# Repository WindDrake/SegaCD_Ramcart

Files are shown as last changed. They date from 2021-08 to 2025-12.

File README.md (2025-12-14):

# SegaCD_Ramcart
 Sega Genesis/Megadrive CD Back-up RAM Cart

 Design done in Kicad 5.1.10 with Digikey libraries. If you want to edit it, you'll need those libraries as well as these files.

 Board tested working 9/3/21 after fixing A20/A22 accidental swap @ U4.

 PCB revision 1.1 has this fixed.
 PCB revision 1.2 adds R2 to make sure the SRAM goes into sleep mode. The BOM has also changed.

 RAM Cart tested 9/3 with Dark Wizard and does not have the save corruption issue that the Castlemania Ultra cart has.

 CSV Format BOM & Gerbers added 10/30/21.

 If you have an Etsy/eBay/Aliexpress/etc. cartridge and are experiencing low battery life, you'll need to swap parts at R1, D1, and U2 with the parts listed in the current BOM. You'll also need to add a 10k resistor from U2 Pin 22 to D1 Pin 3 (the single pin on top).

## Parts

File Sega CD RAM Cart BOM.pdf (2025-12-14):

Source: | \Sega CD Ram Cart\Sega CD RAM Cart.sch
Date: | 10/30/2021 13:53
Tool: | Eeschema (5.1.10)-1
Generator: | \bin\scripting\plugins/bom_csv_grouped_by_value.py
Component Count: | 21
Reference(s) | Value | LibPart | Footprint | Digikey PN
BT1 | Battery_Cell | Sega_Genesis:Battery_Cell | BU2450SM:BAT_BU2450SM-JJ-G | BU2450SM-JJ-GTR
C1-C7 | 0.1uF | Device:C | Capacitor_SMD:C_1206_3216Metric_Pad1.33x1.80mm_HandSolder | C1206C104K4RACTU
C8 | 22uF 25v | Device:CP | Capacitor_THT:CP_Radial_D5.0mm_P2.00mm | 25ML22MEFC5X5
D1 | SDM40E20LC-7 | Sega_Genesis:BAT5405E | digikey-footprints:SOT-23-3 | SDM40E20LC-7
H1, H2 | MountingHole | Mechanical:MountingHole | Sega CD RAM Cart:MountingHole_6.2mm
J1 | Genesis_Edge_Connector | Sega_Genesis:Genesis_Edge_Connector | Sega CD RAM Cart:Genesis_Card_Edge
R1, R2 | 10K | Device:R | Resistor_SMD:R_0805_2012Metric_Pad1.20x1.40mm_HandSolder | RMCF0805FT10K0
U1 | 74LS30 | 74xx:74LS30 | digikey-footprints:SOIC-14_W3.9mm | SN74LS30DR
U2 | CY62148ELL-55SXI | Memory_RAM:IS61C5128AS-25QLI | Package_SO:SSOP-32_11.305x20.495mm_P1.27mm | CY62148ELL-55SXI
U3 | 74LS30 | 74xx:74LS30 | digikey-footprints:SOIC-14_W3.9mm | SN74LS30DR
U4 | 74LS138 | 74xx:74LS138 | digikey-footprints:SOIC-16_W3.90mm | SN74LS138DR
U5 | 74LS32 | 74xx:74LS32 | digikey-footprints:SOIC-14_W3.9mm | SN74LS32DR
U6 | 74LS74 | 74xx:74LS74 | digikey-footprints:SOIC-14_W3.9mm | SN74LS74ADR
U7 | 74LS245 | 74xx:74LS245 | digikey-footprints:SSOP-20_W5.3mm | SN74LS245DBR

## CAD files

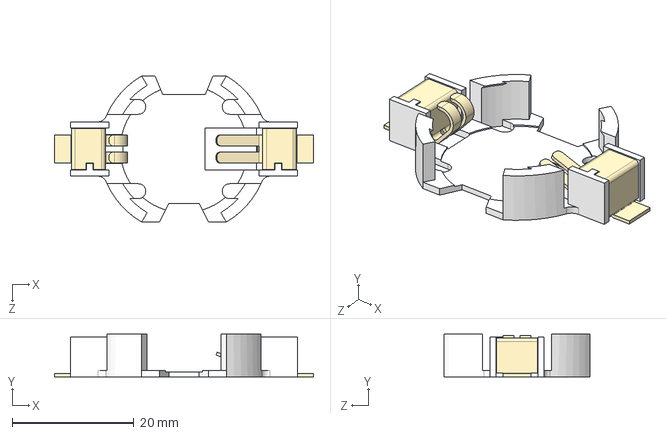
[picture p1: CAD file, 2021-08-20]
BU2450SM/BU2450SM-JJ-G.step
42.5 x 7.00 x 24.0 mm

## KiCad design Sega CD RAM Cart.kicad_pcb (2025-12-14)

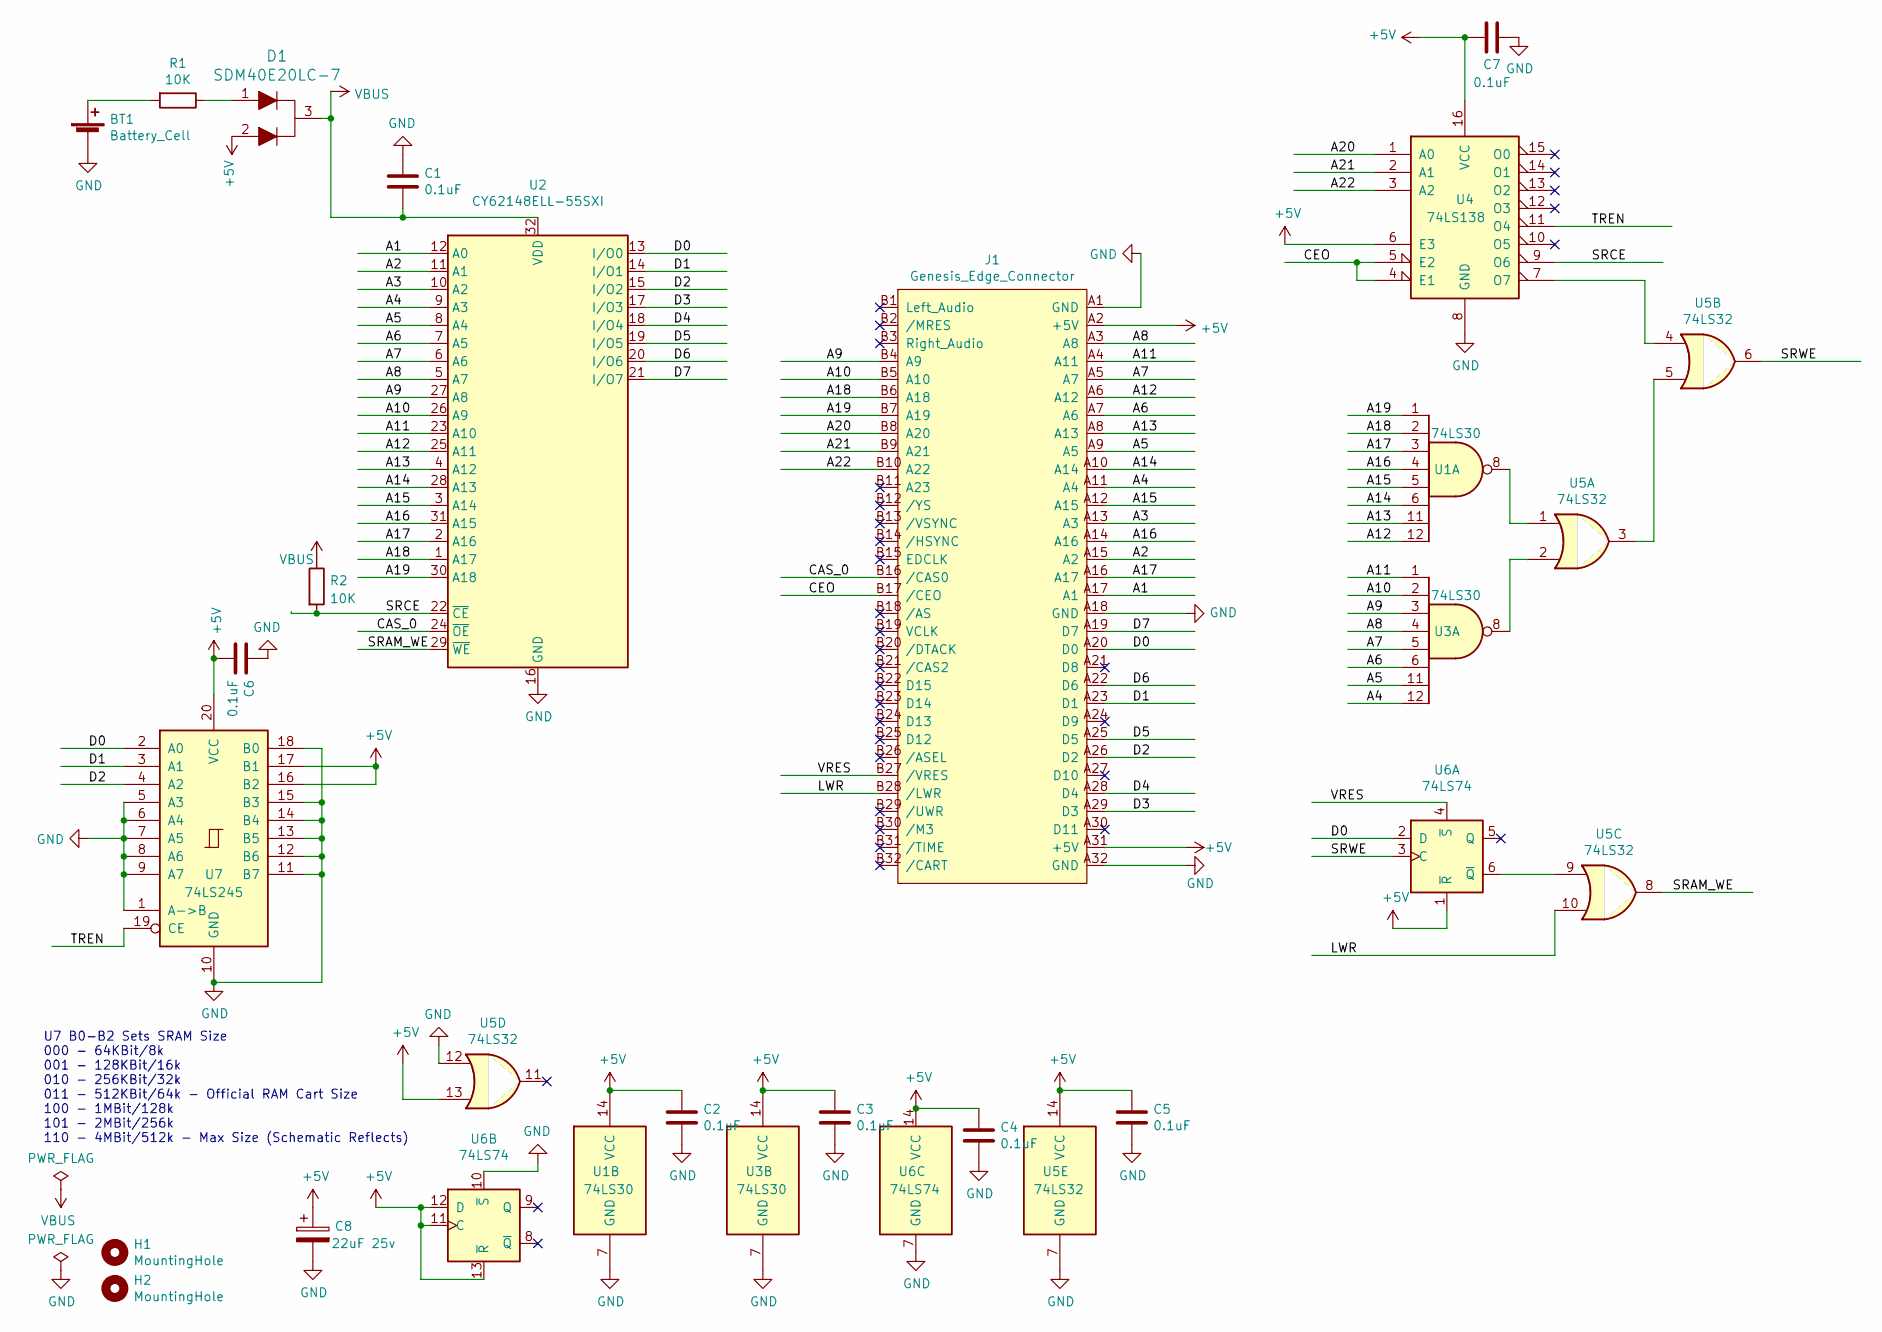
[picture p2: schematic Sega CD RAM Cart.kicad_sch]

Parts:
BT1: Battery_Cell; BAT_BU2450SM-JJ-G; Digikey PN BU2450SM-JJ-GTR
C1, C2, C3, C4, C5, C6, C7: 0.1uF; C_1206_3216Metric_Pad1.33x1.80mm_HandSolder; Digikey PN C1206C104K4RACTU
C8: 22uF 25v; CP_Radial_D5.0mm_P2.00mm; Digikey PN 25ML22MEFC5X5
D1: SDM40E20LC-7; SOT-23-3; Digikey PN SDM40E20LC-7
H1, H2: MountingHole; MountingHole_6.2mm
J1: Genesis_Edge_Connector; Genesis_Card_Edge
R1, R2: 10K; R_0805_2012Metric_Pad1.20x1.40mm_HandSolder; Digikey PN RMCF0805FT10K0
U1, U3: 74LS30; SOIC-14_W3.9mm; Digikey PN SN74LS30DR
U2: CY62148ELL-55SXI; SSOP-32_11.305x20.495mm_P1.27mm; Digikey PN CY62148ELL-55SXI
U4: 74LS138; SOIC-16_W3.90mm; Digikey PN SN74LS138DR
U5: 74LS32; SOIC-14_W3.9mm; Digikey PN SN74LS32DR
U6: 74LS74; SOIC-14_W3.9mm; Digikey PN SN74LS74ADR
U7: 74LS245; SSOP-20_W5.3mm; Digikey PN SN74LS245DBR

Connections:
+5V: C2.1, C3.1, C4.1, C5.1, C6.2, C7.2, C8.1, D1.2, J1.A2 (+5V), J1.A31 (+5V), U1.14 (VCC), U3.14 (VCC), U4.6 (E3), U4.16 (VCC), U5.13, U5.14 (VCC), U6.1 (~R), U6.11 (C), U6.12 (D), U6.13 (~R), U6.14 (VCC), U7.16 (B2), U7.17 (B1), U7.20 (VCC)
/A1: J1.A17 (A1), U2.12 (A0)
/A2: J1.A15 (A2), U2.11 (A1)
/A3: J1.A13 (A3), U2.10 (A2)
/A4: J1.A11 (A4), U2.9 (A3), U3.12
/A5: J1.A9 (A5), U2.8 (A4), U3.11
/A6: J1.A7 (A6), U2.7 (A5), U3.6
/A7: J1.A5 (A7), U2.6 (A6), U3.5
/A8: J1.A3 (A8), U2.5 (A7), U3.4
/A9: J1.B4 (A9), U2.27 (A8), U3.3
/A10: J1.B5 (A10), U2.26 (A9), U3.2
/A11: J1.A4 (A11), U2.23 (A10), U3.1
/A12: J1.A6 (A12), U1.12, U2.25 (A11)
/A13: J1.A8 (A13), U1.11, U2.4 (A12)
/A14: J1.A10 (A14), U1.6, U2.28 (A13)
/A15: J1.A12 (A15), U1.5, U2.3 (A14)
/A16: J1.A14 (A16), U1.4, U2.31 (A15)
/A17: J1.A16 (A17), U1.3, U2.2 (A16)
/A18: J1.B6 (A18), U1.2, U2.1 (A17)
/A19: J1.B7 (A19), U1.1, U2.30 (A18)
/A20: J1.B8 (A20), U4.1 (A0)
/A21: J1.B9 (A21), U4.2 (A1)
/A22: J1.B10 (A22), U4.3 (A2)
/CAS_0: J1.B16 (/CAS0), U2.24 (~OE)
/CEO: J1.B17 (/CEO), U4.4 (E1), U4.5 (E2)
/D0: J1.A20 (D0), U2.13 (I/O0), U6.2 (D), U7.2 (A0)
/D1: J1.A23 (D1), U2.14 (I/O1), U7.3 (A1)
/D2: J1.A26 (D2), U2.15 (I/O2), U7.4 (A2)
/D3: J1.A29 (D3), U2.17 (I/O3)
/D4: J1.A28 (D4), U2.18 (I/O4)
/D5: J1.A25 (D5), U2.19 (I/O5)
/D6: J1.A22 (D6), U2.20 (I/O6)
/D7: J1.A19 (D7), U2.21 (I/O7)
/LWR: J1.B28 (/LWR), U5.10
/SRAM_WE: U2.29 (~WE), U5.8
/SRCE: R2.2, U2.22 (~CE), U4.9 (O6)
/SRWE: U5.6, U6.3 (C)
/TREN: U4.11 (O4), U7.19 (CE)
/VRES: J1.B27 (/VRES), U6.4 (~S)
GND: BT1.N (-), C1.1, C2.2, C3.2, C4.2, C5.2, C6.1, C7.1, C8.2, J1.A1 (GND), J1.A18 (GND), J1.A32 (GND), U1.7 (GND), U2.16 (GND), U3.7 (GND), U4.8 (GND), U5.7 (GND), U5.12, U6.7 (GND), U6.10 (~S), U7.1 (A->B), U7.5 (A3), U7.6 (A4), U7.7 (A5), U7.8 (A6), U7.9 (A7), U7.10 (GND), U7.11 (B7), U7.12 (B6), U7.13 (B5), U7.14 (B4), U7.15 (B3), U7.18 (B0)
unnamed: BT1.P (+), R1.2
unnamed: D1.1, R1.1
unnamed: U1.8, U5.1
unnamed: U3.8, U5.2
unnamed: U4.7 (O7), U5.4
unnamed: U5.3, U5.5
unnamed: U5.9, U6.6 (~Q)
VBUS: C1.2, D1.3, R2.1, U2.32 (VDD)

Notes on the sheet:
U7 B0-B2 Sets SRAM Size 000 - 64KBit/8k 001 - 128KBit/16k 010 - 256KBit/32k 011 - 512KBit/64k - Official RAM Cart Size 100 - 1MBit/128k 101 - 2MBit/256k 110 - 4MBit/512k - Max Size (Schematic Reflects)

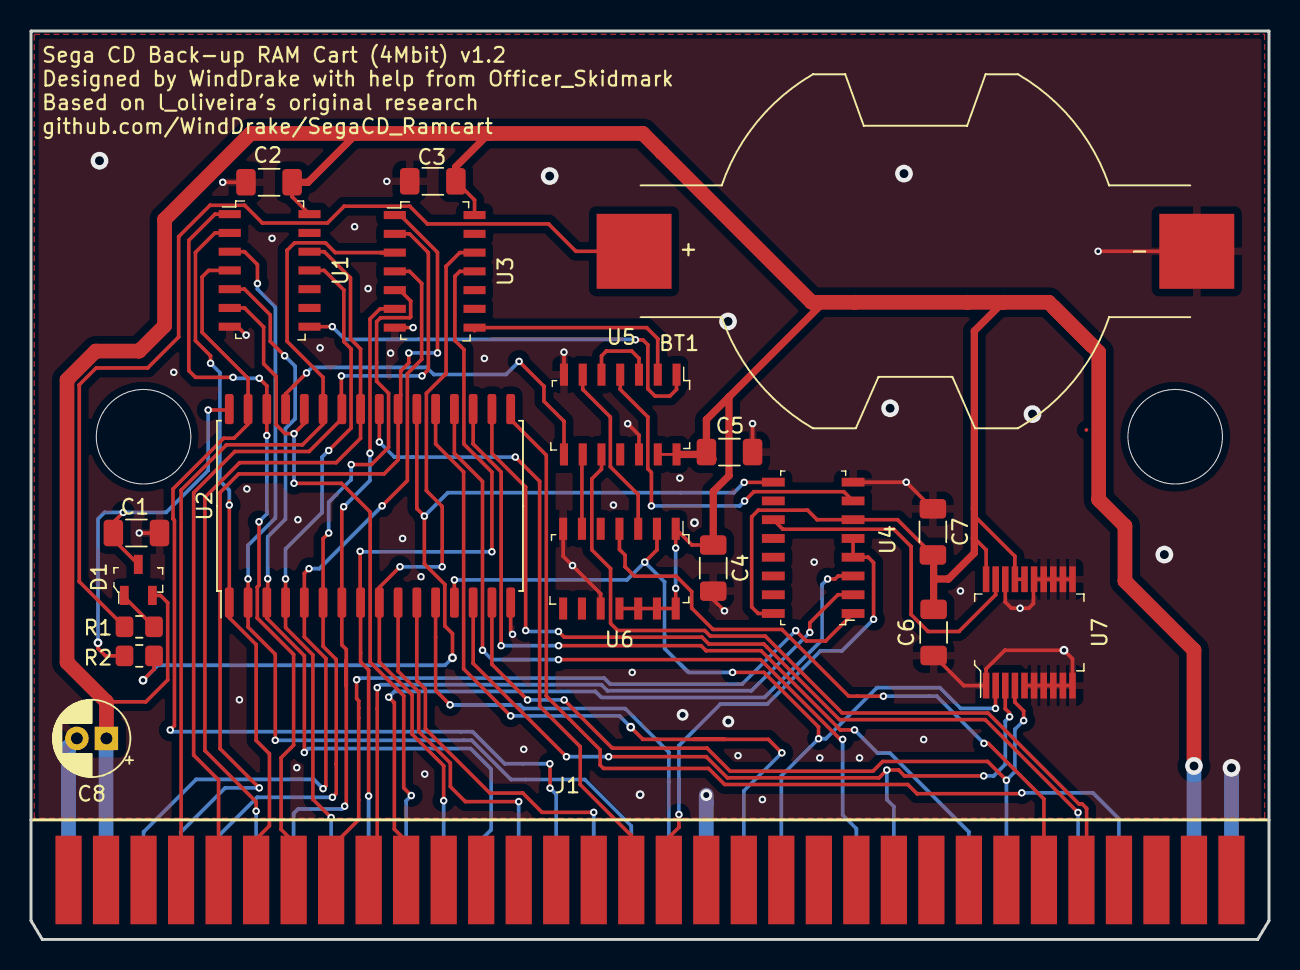
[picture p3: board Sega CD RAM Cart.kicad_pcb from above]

Board: 2 copper layers, 83.8 x 61.5 mm, 22 parts (0 on the bottom side), 48 nets.

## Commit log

2021-08-20 First upload.
    [BU2450SM-JJ-G.step, Sega CD RAM Cart.kicad_pcb, Sega CD RAM Cart.sch]
2021-08-20 Finalizing design.
    [Sega CD RAM Cart.kicad_pcb, Sega CD RAM Cart.sch]
2021-08-20 More cleanup.
    Boards approaching final rev. Added OSHW logos & other stuff.
    [Sega CD RAM Cart.kicad_pcb, Sega CD RAM Cart.sch]
2021-08-21 Last Rev - PCB's Ordered
    Full 1.0 revision is complete. PCB's ordered today through OSHPark.
    [Sega CD RAM Cart.kicad_pcb]
2021-09-01 Board tweaks.
    U5D OR Gate inputs tied up so they don't float. No other changes.
    [Sega CD RAM Cart.kicad_pcb, Sega CD RAM Cart.sch]
2021-09-03 Board Updates (+Board tested!)
    Removed unneeded files, fixed A20/A22 swap @ U4. Boards tested working today after cut & jumper on the real PCB's.
    [Sega CD RAM Cart.kicad_pcb, Sega CD RAM Cart.sch]
2021-09-04 BOM Fix
    Realized I specified a 1206 resistor instead of 0805. Fixed the BOM. Also added an HTML exported BOM for easy reading.
    [Sega CD RAM Cart.kicad_pcb, Sega CD RAM Cart.sch]
2021-10-30 Create Sega CD RAM Cart.csv
    Added CSV BOM.
    [Sega CD RAM Cart.csv]
2021-10-30 Added Gerbers.
2021-11-13 Final label & BOM.
    Final label has been completed (.PSD format) and a spelling error in the .xml BOM. Project at this point is complete.
2025-12-14 1.2 Overhaul
    Changed SRAM, protection diode, protection resistor to fix battery lifetime problem. Added R2 to fix lack of sleep mode.
    [Sega CD RAM Cart BOM.csv, Sega CD RAM Cart.csv, Sega CD RAM Cart.kicad_pcb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]
